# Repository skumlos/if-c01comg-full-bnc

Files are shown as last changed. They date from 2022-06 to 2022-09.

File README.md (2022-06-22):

IF-C01COMG Full BNC Clone board SMD

This is a full sized version of the IF-C01COMG board for JVC pro monitors (TM-Hxx50CG) and some others...

It is created as a very close to 1:1 copy of the original (sans the stereo-to-mono mixing circuit and internal 75R term option)
thus it has dual stack BNCs, which are pretty expensive, to allow for passthrough of video signals.

Board is for now completely untested...

You're welcome to clone, sell, re-design and whatever, see LICENSE.

(2022) Martin Hejnfelt (martin@hejnfelt.com)
This work is free. You can redistribute it and/or modify it under the
terms of the Do What The Fuck You Want To Public License, Version 2,
as published by Sam Hocevar. See the LICENSE file for more details.

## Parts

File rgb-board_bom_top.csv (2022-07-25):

Comment | Designator | Footprint | LCSC Part #
47uF/25V | C101 C102 C103 | SMD,6.3x6.1mm | C88810
10uF/50V | C104 C105 | SMD,5x5.4mm | C445070
OPT | C106 C108 C110 C112 C113
100nF | C114 C116 C117 C118 C119 C206 | 0805 | C1711
100uF/16 | C115 C207 C107 C109 C111 | SMD,6.3x5.4mm | C442615
10uF/25V | C120 C122 | SMD,5x5.4mm | C445070
1uF/25V | C121 | 0805 | C28323
180pF | C201 C202 C205 | 0805 | C113826
1uF/50V | C203 | SMD,4x5.4mm | C445065
39pF | C204 | 0805 | C527185
BAT46W | D101 D102 D103 D104 D105 D106 D107 D108 D109 D110 | SOD-123 | C83152
BZT52C12 | D201 | SOD-123 | C177013
Conn_02x25_Odd_Even | J1
MountingHole | J3 J4
73415-3980 | J5 J6 J7 J8 J9
RCJ-2223 | J10
BC850C | Q101 Q105 Q109 Q113 Q114 Q201 Q102 Q103 Q106 Q107 Q110 Q111 | SOT-23(SOT-23-3) | C78484
470R | R1 R2 R109 R112 R123 R126 R137 R140 R161 R162 R163 | 0805 | C114564
20K | R3 | 0805 | C114566
75 | R101 R115 R129 R143 R152 | 0805 | C141697
OPT | R103 R131 R145 R154 | 0805 | C105577
100 | R104 R114 R117 R118 R128 R132 R142 R146 R155 | 0805 | C105577
56k | R105 R119 R133 R203 R164 R165 R166 | 0805 | C137509
33k | R106 R120 R134 R147 R148 R156 R157 | 0805 | C141696
1.5k | R107 R121 R135 | 0805 | C114555
390 | R113 R127 R141 | 0805 | C114543
2.7k | R149 R158 R205 | 0805 | C144567
OPT | R151 R160 | 0805 | C144567
OPT | R201 | 0805 | C95781
1K | R202 | 0805 | C95781
68K | R204 | 0805 | C228958
JS202011SCQN | SW10 SW101 SW105 SW129 SW143 SW152 | SMD | C221666
NCP1117-12_SOT223 | U1
15pF | C124 C125 C126 | 0805
BC860C | Q104 Q108 Q112 | SOT-23 | C454976
OPT | Q115 Q116 Q117
OPT | R108 R122 R136
47k | R111 R125 R139 | 0805 | C126351
500R | RV101 RV102 RV103

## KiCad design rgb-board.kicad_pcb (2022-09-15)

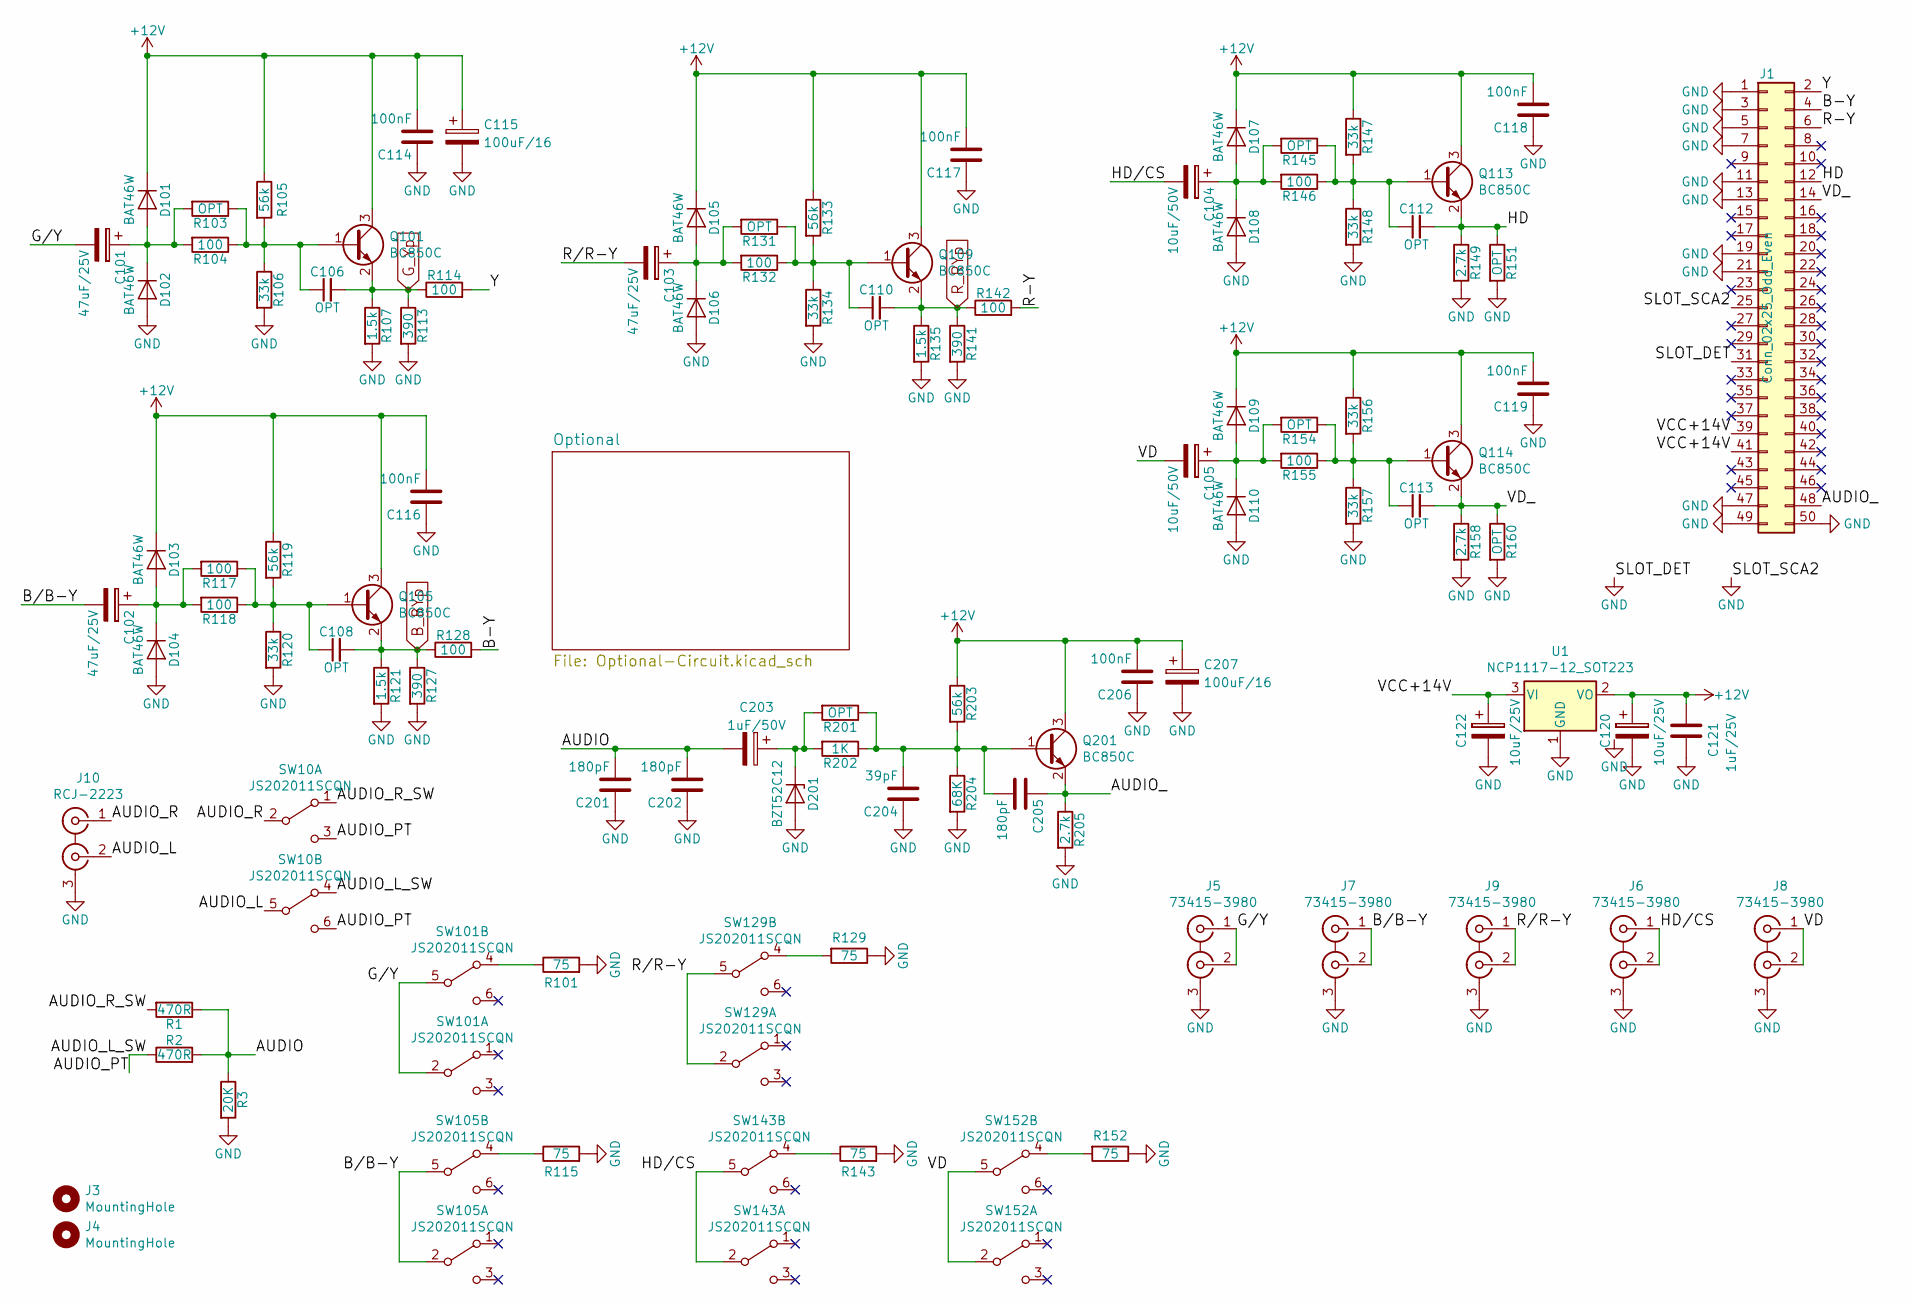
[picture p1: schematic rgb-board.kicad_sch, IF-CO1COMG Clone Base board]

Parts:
C101, C102, C103: 47uF/25V; C_Elec_6.3x5.4; JLC SMD,6.3x6.1mm
C104, C105: 10uF/50V; C_Elec_5x5.4; JLC SMD,5x5.4mm
C106, C108, C110, C112, C113: OPT; C_0805_2012Metric_Pad1.18x1.45mm_HandSolder
C114, C116, C117, C118, C119, C206: 100nF; C_0805_2012Metric_Pad1.18x1.45mm_HandSolder; JLC 0805
C115, C207: 100uF/16; CP_Elec_6.3x5.4; JLC SMD,6.3x5.4mm
C120, C122: 10uF/25V; C_Elec_5x5.4; JLC SMD,5x5.4mm
C121: 1uF/25V; C_0805_2012Metric_Pad1.18x1.45mm_HandSolder; JLC 0805
C201, C202, C205: 180pF; C_0805_2012Metric_Pad1.18x1.45mm_HandSolder; JLC 0805
C203: 1uF/50V; CP_Elec_4x5.4; JLC SMD,4x5.4mm
C204: 39pF; C_0805_2012Metric_Pad1.18x1.45mm_HandSolder; JLC 0805
D101, D102, D103, D104, D105, D106, D107, D108, D109, D110: BAT46W; D_SOD-123; JLC SOD-123
D201: BZT52C12; D_SOD-123; JLC SOD-123
J1: Conn_02x25_Odd_Even; Pin_Header_Angled_2x25_Pitch2.54mm
J3, J4: MountingHole; MountingHole_3.2mm_M3
J5, J6, J7, J8, J9: 73415-3980
J10: RCJ-2223; RCJ-22XX
Q101, Q105, Q109, Q113, Q114, Q201: BC850C; SOT-23_Handsoldering; JLC SOT-23(SOT-23-3)
R1, R2: 470R; R_0805_2012Metric_Pad1.20x1.40mm_HandSolder; JLC 0805
R3: 20K; R_0805_2012Metric_Pad1.20x1.40mm_HandSolder; JLC 0805
R101, R115, R129, R143, R152: 75; R_0805_2012Metric_Pad1.20x1.40mm_HandSolder; JLC 0805
R103, R131, R145, R151, R154, R160, R201: OPT; R_0805_2012Metric_Pad1.20x1.40mm_HandSolder; JLC 0805
R104, R114, R117, R118, R128, R132, R142, R146, R155: 100; R_0805_2012Metric_Pad1.20x1.40mm_HandSolder; JLC 0805
R105, R119, R133, R203: 56k; R_0805_2012Metric_Pad1.20x1.40mm_HandSolder; JLC 0805
R106, R120, R134, R147, R148, R156, R157: 33k; R_0805_2012Metric_Pad1.20x1.40mm_HandSolder; JLC 0805
R107, R121, R135: 1.5k; R_0805_2012Metric_Pad1.20x1.40mm_HandSolder; JLC 0805
R113, R127, R141: 390; R_0805_2012Metric_Pad1.20x1.40mm_HandSolder; JLC 0805
R149, R158, R205: 2.7k; R_0805_2012Metric_Pad1.20x1.40mm_HandSolder; JLC 0805
R202: 1K; R_0805_2012Metric_Pad1.20x1.40mm_HandSolder; JLC 0805
R204: 68K; R_0805_2012Metric_Pad1.20x1.40mm_HandSolder; JLC 0805
SW10, SW101, SW105, SW129, SW143, SW152: JS202011SCQN; JLC SMD
U1: NCP1117-12_SOT223; SOT-223-3_TabPin2

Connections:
+12V: C114.2, C115.1, C116.2, C117.2, C118.2, C119.2, C120.1, C121.2, C206.2, C207.1, D101.1 (K), D103.1 (K), D105.1 (K), D107.1 (K), D109.1 (K), Q101.3 (C), Q105.3 (C), Q109.3 (C), Q113.3 (C), Q114.3 (C), Q201.3 (C), R105.1, R119.1, R133.1, R147.1, R156.1, R203.1, U1.2 (VO); also elsewhere on the board
/AUDIO: C201.2, C202.2, C203.2, R1.1, R2.2, R3.1
/AUDIO_: C205.1, J1.48, Q201.2 (E), R205.1
/AUDIO_L: J10.2 (IN2), SW10.5 (B)
/AUDIO_L_SW: R2.1, SW10.3 (C), SW10.4 (A), SW10.6 (C)
/AUDIO_R: J10.1 (IN1), SW10.2 (B)
/AUDIO_R_SW: R1.2, SW10.1 (A)
/B-Y: J1.4, R128.2
/B/B-Y: C102.2, J7.1 (IN1), J7.2 (IN2), SW105.2 (B), SW105.5 (B)
/G/Y: C101.2, J5.1 (IN1), J5.2 (IN2), SW101.2 (B), SW101.5 (B)
/HD: C112.2, J1.12, Q113.2 (E), R149.1, R151.1
/HD/CS: C104.2, J6.1 (IN1), J6.2 (IN2), SW143.2 (B), SW143.5 (B)
/R-Y: J1.6, R142.2
/R/R-Y: C103.2, J9.1 (IN1), J9.2 (IN2), SW129.2 (B), SW129.5 (B)
/VCC+14V: C122.1, J1.39, J1.41, U1.3 (VI)
/VD: C105.2, J8.1 (IN1), J8.2 (IN2), SW152.2 (B), SW152.5 (B)
/VD_: C113.2, J1.14, Q114.2 (E), R158.1, R160.1
/Y: J1.2, R114.2
B_BYp: C108.2, Q105.2 (E), R121.1, R127.1, R128.1; also elsewhere on the board
GND: C114.1, C115.2, C116.1, C117.1, C118.1, C119.1, C120.2, C121.1, C122.2, C201.1, C202.1, C204.1, C206.1, C207.2, D102.2 (A), D104.2 (A), D106.2 (A), D108.2 (A), D110.2 (A), D201.2 (A), J1.1, J1.3, J1.5, J1.7, J1.11, J1.13, J1.19, J1.21, J1.25, J1.31, J1.47, J1.49, J1.50, J5.3 (EXT), J6.3 (EXT), J7.3 (EXT), J8.3 (EXT), J9.3 (EXT), J10.3 (EXT), R3.2, R101.2, R106.2, R107.2, R113.2, R115.2, R120.2, R121.2, R127.2, R129.1, R134.2, R135.2, R141.2, R143.2, R148.2, R149.2, R151.2, R152.1, R157.2, R158.2, R160.2, R204.2, R205.2, U1.1 (GND); also elsewhere on the board
G_Yp: C106.2, Q101.2 (E), R107.1, R113.1, R114.1; also elsewhere on the board
unnamed: C101.1, D101.2 (A), D102.1 (K), R103.2, R104.2
unnamed: C102.1, D103.2 (A), D104.1 (K), R117.2, R118.2
unnamed: C103.1, D105.2 (A), D106.1 (K), R131.2, R132.2
unnamed: C104.1, D107.2 (A), D108.1 (K), R145.2, R146.2
unnamed: C105.1, D109.2 (A), D110.1 (K), R154.2, R155.2
unnamed: C106.1, Q101.1 (B), R103.1, R104.1, R105.2, R106.1
unnamed: C108.1, Q105.1 (B), R117.1, R118.1, R119.2, R120.1
unnamed: C110.1, Q109.1 (B), R131.1, R132.1, R133.2, R134.1
unnamed: C112.1, Q113.1 (B), R145.1, R146.1, R147.2, R148.1
unnamed: C113.1, Q114.1 (B), R154.1, R155.1, R156.2, R157.1
unnamed: C203.1, D201.1 (K), R201.2, R202.2
unnamed: C204.2, C205.2, Q201.1 (B), R201.1, R202.1, R203.2, R204.1
unnamed: R101.1, SW101.4 (A)
unnamed: R115.1, SW105.4 (A)
unnamed: R129.2, SW129.4 (A)
unnamed: R143.1, SW143.4 (A)
unnamed: R152.2, SW152.4 (A)
R_RYp: C110.2, Q109.2 (E), R135.1, R141.1, R142.1; also elsewhere on the board

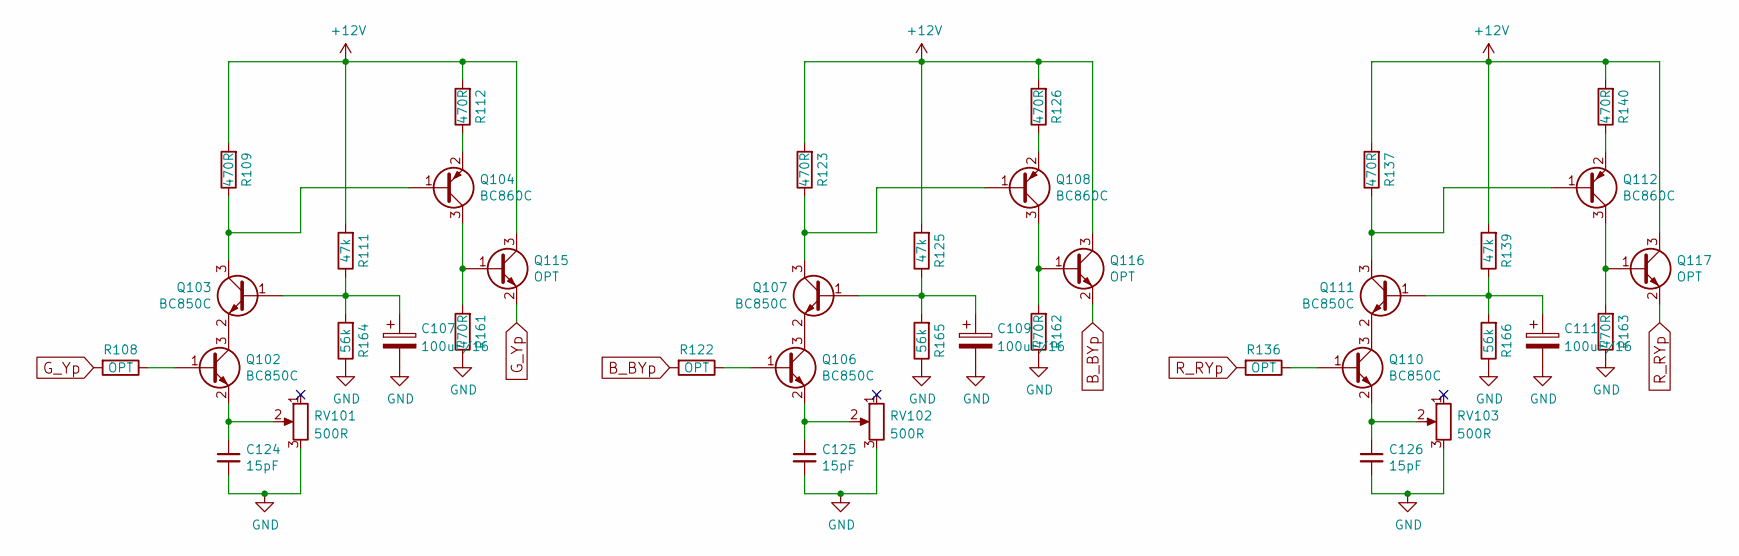
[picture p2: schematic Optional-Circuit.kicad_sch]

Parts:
C107, C109, C111: 100uF/16; CP_Elec_6.3x5.4; JLC SMD,6.3x5.4mm
C124, C125, C126: 15pF; C_0805_2012Metric_Pad1.18x1.45mm_HandSolder; JLC 0805
Q102, Q103, Q106, Q107, Q110, Q111: BC850C; SOT-23_Handsoldering; JLC SOT-23(SOT-23-3)
Q104, Q108, Q112: BC860C; SOT-23_Handsoldering; JLC SOT-23
Q115, Q116, Q117: OPT; SOT-23_Handsoldering
R108, R122, R136: OPT; R_0805_2012Metric_Pad1.20x1.40mm_HandSolder
R109, R112, R123, R126, R137, R140, R161, R162, R163: 470R; R_0805_2012Metric_Pad1.20x1.40mm_HandSolder; JLC 0805
R111, R125, R139: 47k; R_0805_2012Metric_Pad1.20x1.40mm_HandSolder; JLC 0805
R164, R165, R166: 56k; R_0805_2012Metric_Pad1.20x1.40mm_HandSolder; JLC 0805
RV101, RV102, RV103: 500R; Potentiometer_Bourns_3386P_Vertical

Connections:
+12V: Q115.3 (C), Q116.3 (C), Q117.3 (C), R109.2, R111.2, R112.2, R123.2, R125.2, R126.2, R137.2, R139.2, R140.2; also elsewhere on the board
B_BYp: Q116.2 (E), R122.2; also elsewhere on the board
GND: C107.2, C109.2, C111.2, C124.2, C125.2, C126.2, R161.1, R162.1, R163.1, R164.1, R165.1, R166.1, RV101.3, RV102.3, RV103.3; also elsewhere on the board
G_Yp: Q115.2 (E), R108.2; also elsewhere on the board
unnamed: C107.1, Q103.1 (B), R111.1, R164.2
unnamed: C109.1, Q107.1 (B), R125.1, R165.2
unnamed: C111.1, Q111.1 (B), R139.1, R166.2
unnamed: C124.1, Q102.2 (E), RV101.2
unnamed: C125.1, Q106.2 (E), RV102.2
unnamed: C126.1, Q110.2 (E), RV103.2
unnamed: Q102.1 (B), R108.1
unnamed: Q102.3 (C), Q103.2 (E)
unnamed: Q103.3 (C), Q104.1 (B), R109.1
unnamed: Q104.2 (E), R112.1
unnamed: Q104.3 (C), Q115.1 (B), R161.2
unnamed: Q106.1 (B), R122.1
unnamed: Q106.3 (C), Q107.2 (E)
unnamed: Q107.3 (C), Q108.1 (B), R123.1
unnamed: Q108.2 (E), R126.1
unnamed: Q108.3 (C), Q116.1 (B), R162.2
unnamed: Q110.1 (B), R136.1
unnamed: Q110.3 (C), Q111.2 (E)
unnamed: Q111.3 (C), Q112.1 (B), R137.1
unnamed: Q112.2 (E), R140.1
unnamed: Q112.3 (C), Q117.1 (B), R163.2
R_RYp: Q117.2 (E), R136.2; also elsewhere on the board

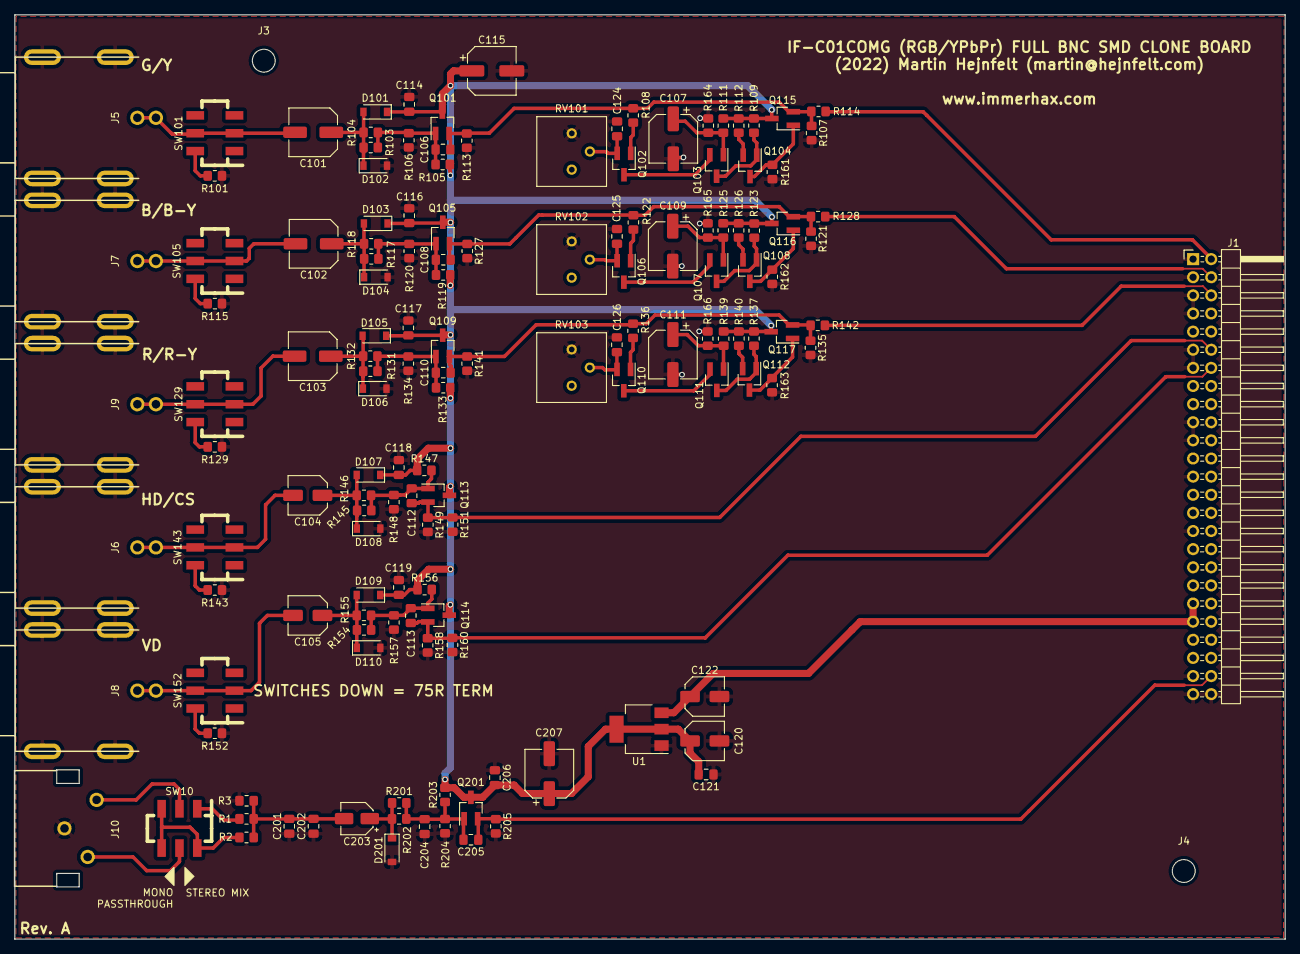
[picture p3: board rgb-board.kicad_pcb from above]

Board: 2 copper layers, 178.0 x 129.5 mm, 144 parts (0 on the bottom side), 60 nets.

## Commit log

2022-07-25 Add optional segments, update to Kicad 6
    [Optional-Circuit.kicad_sch, Optional-Circuit.sch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]
2022-09-15 Update PCB, and plots
    [rgb-board-B.Cu.gbr, rgb-board-B.Mask.gbr, rgb-board-B.SilkS.gbr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]
